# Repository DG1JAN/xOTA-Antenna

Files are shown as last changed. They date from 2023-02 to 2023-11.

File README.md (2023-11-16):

# xOTA-Antenna
**A pcb for end fed antennas (EFHW, random wire) for SOTA, POTA,... xOTA** <br /><br />
maximum power rating:
* FT-140-43: 100W SSB/CW or 50W FT8 (etc)
* FT-114-43: 25W SSB/CW or 10W FT8 (etc)
* FT-82-43: 10W SSB/CM or 5W FT8 (etc)
<br />

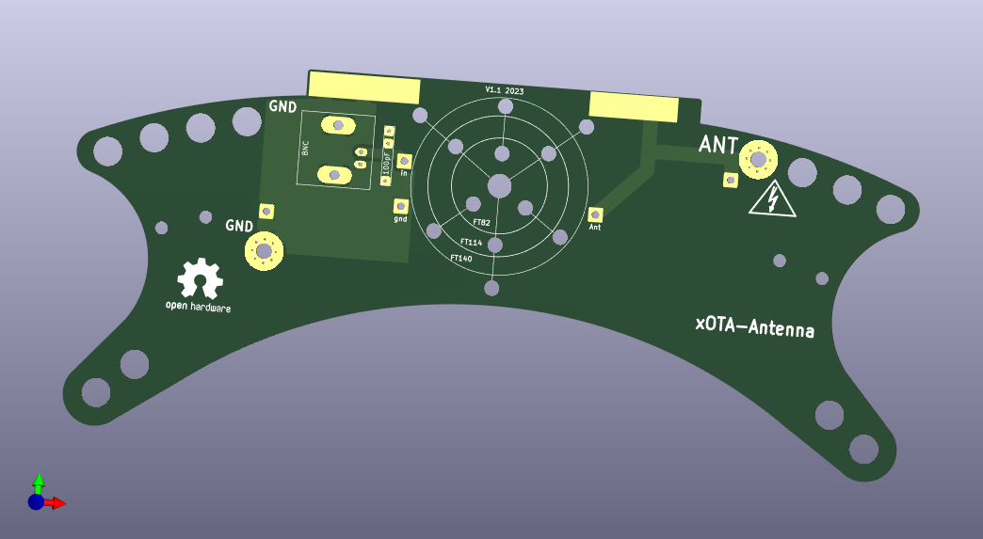
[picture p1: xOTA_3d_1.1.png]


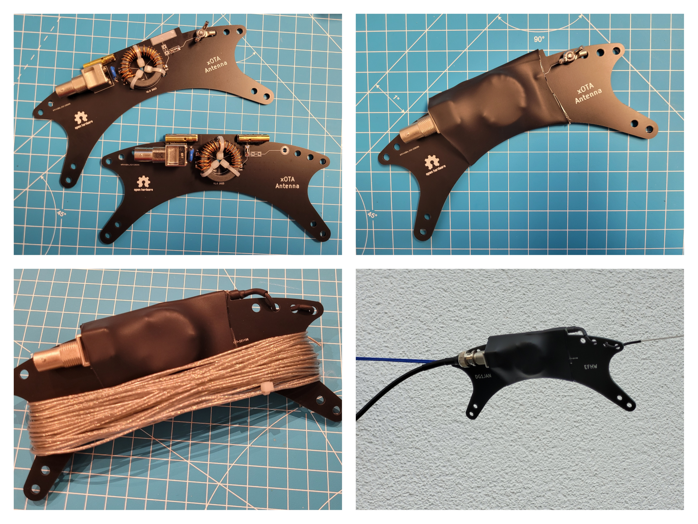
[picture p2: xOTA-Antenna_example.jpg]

(*the two bottom pictures are from the prev. proto desig (labeled as "EFHW" instead of "xOTA-Antenna") and Version 1.0.

## BOM (1:49 UnUn for EFHW*)
*The PCB can also be used with other UnUn windings (like 1:9) to build non resonant ("random wire") endfed antennas.
(links to Distributors are only examples)

1x PCB: custom order from PCB manufacturer e.g. from https://www.jlcpcb.com or https://aisler.net/

*here you can find the gerber files as ZIP-Archive: https://github.com/DG1JAN/xOTA-Antenna/blob/main/xota-gerber.zip <br />
Manuel (Dl2MAN) has made a good video to explain the ordering process for JLCPCB and Aisler: https://www.youtube.com/watch?v=1b3oLp7s9gk&t=202s*

1x Torroid	- e.g. FT140-43, Fair-Rite	5943001001 (AKA Amidon FT114-43) or FT82-43 [with reduced power rating])	
https://www.digikey.de/de/products/detail/fair-rite-products-corp/5943001001/8599631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

1x BNC Socket - Molex	731385033	(Hint: Using alternative Parts might be possible, take care about clearance between PCB and BNC-Plug (most BNC-Sockets are lower, so you cant connect a plug to the socket when soldert on PCB)
https://www.digikey.de/de/products/detail/molex/0731385033/1465137?s=N4IgTCBcDaKHAEAGA7AZgIwoBwFYEpXCALoC%2BQA

1x 100pF 1kV Ceramic Capaciator - e.g. Kemet	C333C101KDG5TA	
https://www.digikey.de/de/products/detail/kemet/C333C101KDG5TA/6161481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

1 meter Trafo wire - e.g. BLOCK	CUL 100/0,63mm (for 100W Version better 1mm)	
https://www.reichelt.de/100g-kupferlackdraht-auf-spule-0-63mm-cul-100-0-63-p57183.html?&nbc=1

2x 4mm Banana Socket - e.g.	GTIWUNG	4mm Plug	(In alternativ/addition to the Banana Sockets, you can also use 3mm Screws with Wingnuts for Antenna (and Ground radial - if so)
https://www.amazon.de/GTIWUNG-Vergoldete-Bananenstecker-Elektronische-Kugelstecker/dp/B07VYSN74H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

8 cm Shrink tube 40mm wide - e.g. ISOLATECH	Shrink Tube 40mm  3:1 with glue	
https://www.amazon.de/gp/product/B06WVCGD7M/ref=ppx_yo_dt_b_asin_title_o09_s01?ie=UTF8&psc=1

---------------------

Take care about clearance between PCB and BNC-Plug (most BNC-Sockets are lower, so you cant connect a plug to the socket when soldert on PCB), use  Molex	"731385033" or similar.	 
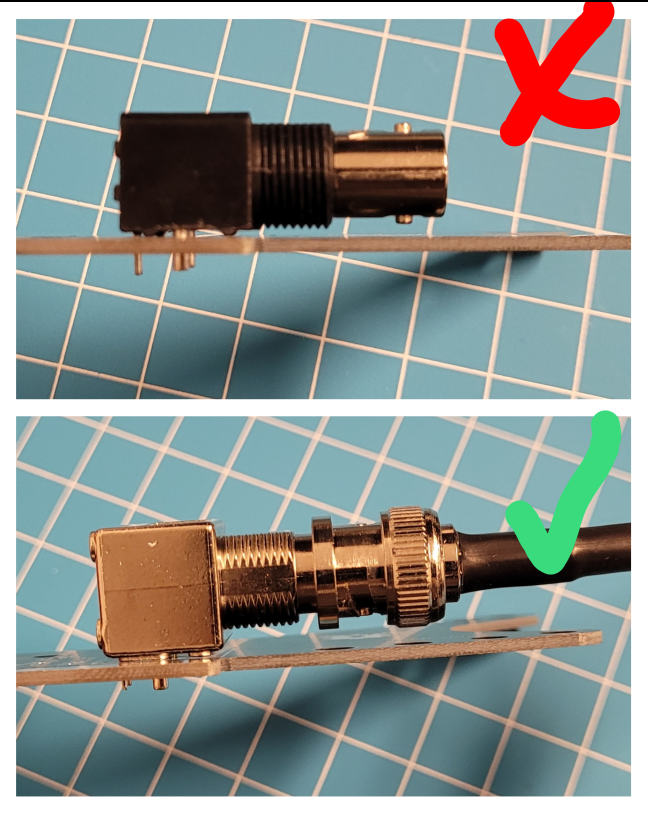
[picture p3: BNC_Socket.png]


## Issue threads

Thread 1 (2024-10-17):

GND hole is to small for (twisted) 1mm wire in EFHW config.

ph2lb, 2024-10-17:
When building the 100W version EFHW with FT140-43 core and 1mm wire, the twisted wire doesn't fit into the GND hole.
I fixed it by using a "hair pin" wire (a loop made of 0.6mm zilver wire pulled through the hole pulling the twisted wire on the the GND pad) , but it would be great if there was a bigger hole, or 2 holes of the current size next to each other.

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

But overall very happy with the idea and result.

73 Lex PH2LB

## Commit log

2023-02-03 INitial Upload V1.0
    [xOTA-B_Cu.gbr, xOTA-B_Mask.gbr, xOTA-B_Paste.gbr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]
2023-02-03 update BOM
    [xOTA-BOM.ods]
2023-08-31 clean up
    [xOTA-B_Cu.gbr, xOTA-B_Mask.gbr, xOTA-B_Paste.gbr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]
2023-08-31 Upload Version 1.1
    [xOTA.kicad_pcb]
2023-08-31 Upload 1:5 edition of xOTA Winder
    [xOTA_1to5_1.0.kicad_pcb]
2023-11-16 clean up for version 1.1
    [xOTA-BOM.ods, xOTA.kicad_pcb, xOTA_1to5_1.0.kicad_pcb]
2023-11-16 upload v1.1
    [xOTA.kicad_pcb]
